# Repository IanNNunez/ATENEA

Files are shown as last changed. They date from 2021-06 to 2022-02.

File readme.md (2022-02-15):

Athena is a TKL keyboard inspired by https://github.com/coseyfannitutti/ mysterium. It uses some of cftkb's kicad libraries
as well as its USBaspLoader build. 

Known issues:
	- Diode 84 is not directly connected to the MCU, it will be fixed for the next revision.
	- Some traces near the FN key could not be completed in the manufacturing process, more clearence is needed.
	- The silkscreen for the BOOT and RESET buttons are not visible, new and clearer silkscreens will be added.
	- The MOSI and MISO pins on the MCU are swapped, does not affect the behaviour of the keyboard it needs to be taken into account when uploading the firmware. It will be fixed for the next revision.
	- The 2u backspace key is not in the correct position, it will be fixed for the next revision.

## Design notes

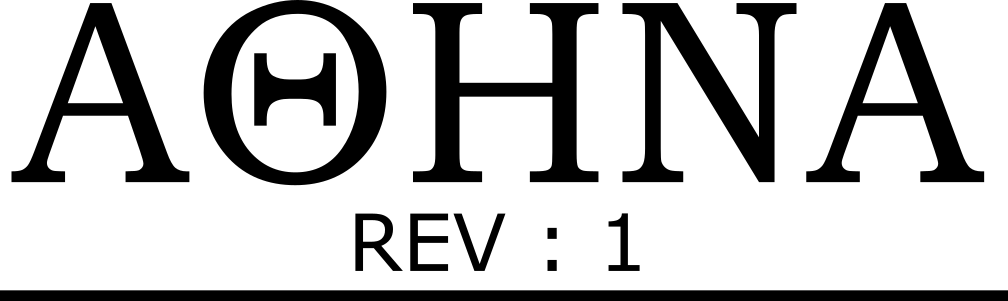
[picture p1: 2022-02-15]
AteneaTKL-pcb/Graphics/text981.png

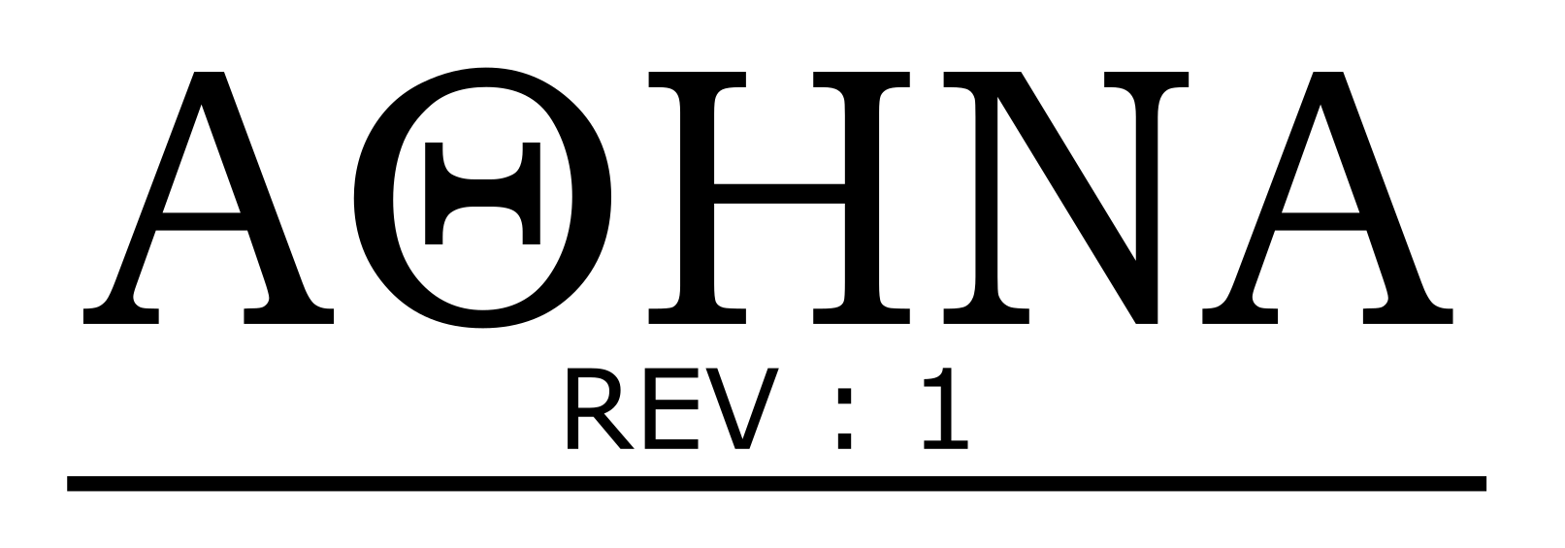
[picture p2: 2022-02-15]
AteneaTKL-pcb/Graphics/rect835.png

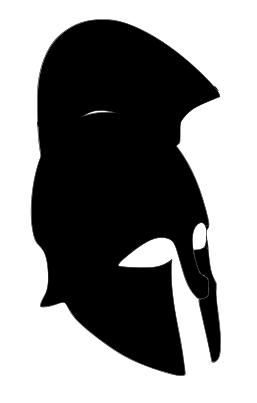
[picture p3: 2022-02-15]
AteneaTKL-pcb/Graphics/athena helmet.png

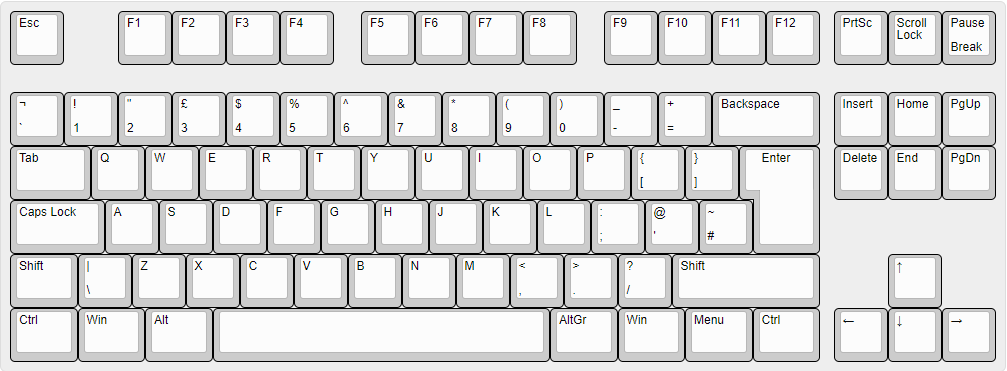
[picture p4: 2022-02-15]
AteneaTKL-pcb/Graphics/Athenea ISO.png

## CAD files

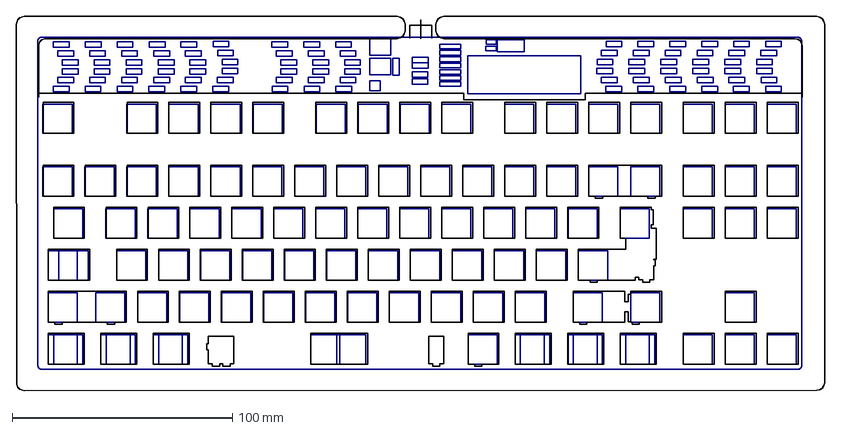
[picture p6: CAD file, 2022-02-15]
AteneaTKL-pcb/Atenea/Atenea-brd.dxf
366.7 x 169.7 mm

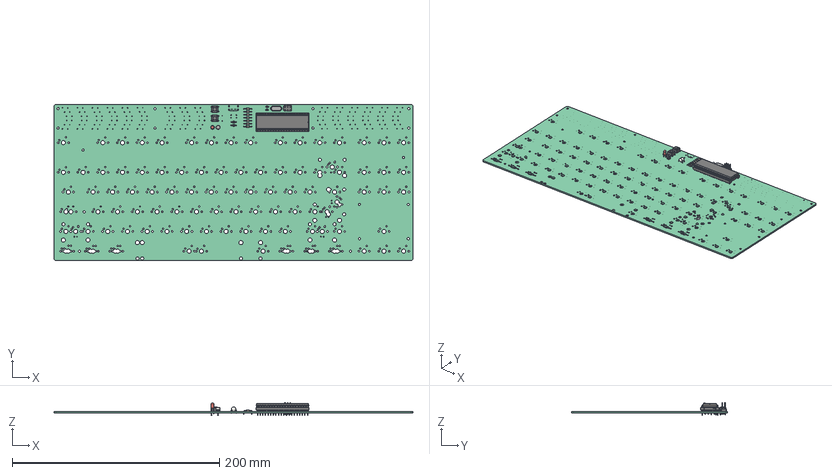
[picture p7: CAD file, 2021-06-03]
AthenaTKL case/3D RENDER/AthenaTKL_PCB.FCStd
346.7 x 150.7 x 12.3 mm
Pcb_5695
R8_R_Axial_DIN0204_L36mm_D16mm_P762mm_Horizontal_5FE505FF
LED1_LED_D3.0mm_5FE505C5
Y1_Crystal_HC49-4H_Vertical_5FE550AE
SW1_SW_PUSH_6mm_5FE54CE4
SW2_SW_PUSH_6mm_5FE5501A
J2_PinHeader_2x03_P254mm_Vertical_5FE54D8D[2]
R2_R_Axial_DIN0204_L36mm_D16mm_P762mm_Horizontal_5FE54EBF
R3_R_Axial_DIN0204_L36mm_D16mm_P762mm_Horizontal_5FE54C7C
R4_R_Axial_DIN0204_L36mm_D16mm_P762mm_Horizontal_5FE54BDD
R5_R_Axial_DIN0204_L36mm_D16mm_P762mm_Horizontal_5FE5506C
R6_R_Axial_DIN0204_L36mm_D16mm_P762mm_Horizontal_5FE54E7D
R7_R_Axial_DIN0204_L36mm_D16mm_P762mm_Horizontal_5FE518E0
C1_C_Disc_D30mm_W16mm_P250mm_5FE51B44
C3_CP_Radial_D40mm_P150mm_5FE51DCC
C5_C_Disc_D43mm_W19mm_P500mm_5FE5F764
C4_C_Disc_D43mm_W19mm_P500mm_5FE5F6FF
C2_C_Disc_D30mm_W16mm_P250mm_5FE518AA
U1_DIP-40_W15.24mm_5FE51992
U1_DIP_40_W1524mm_Socket_5FE51992[2]

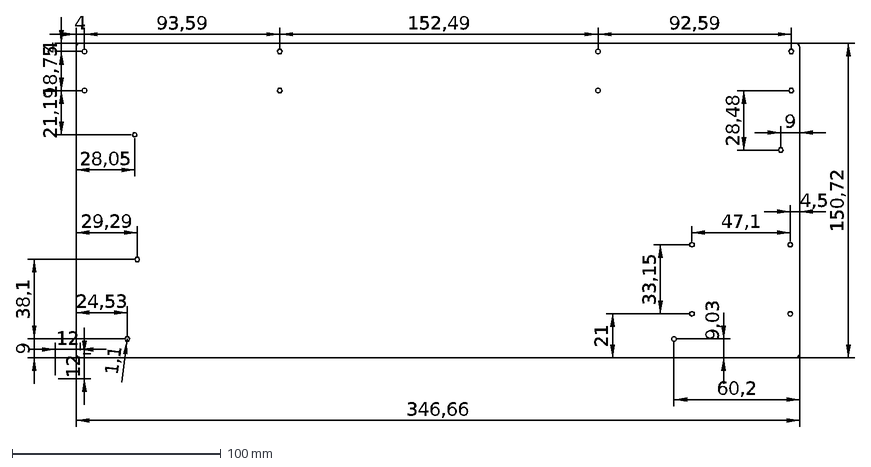
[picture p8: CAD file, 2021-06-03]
AthenaTKL case/Bottom plate.dxf
346,66
150,72
4
93,59
152,49
92,59
18,75
21,19
28,48
33,15
21
9
38,1
9,03
28,05
24,53
60,2
47,1
4,5
29,29
12
1,1

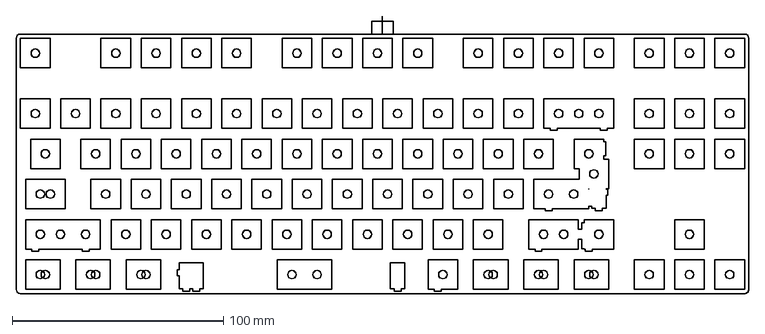
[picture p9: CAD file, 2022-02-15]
AthenaTKL case/CAD misc/TKL Leyout.dxf
346.6 x 131.2 mm

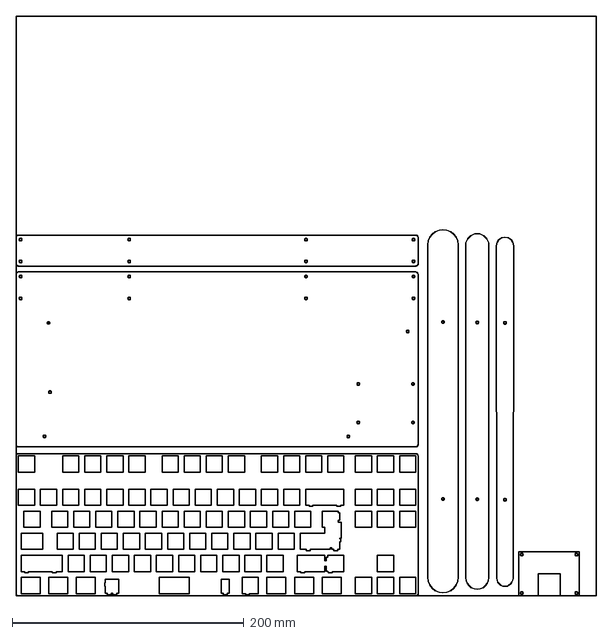
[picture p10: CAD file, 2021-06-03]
AthenaTKL case/CASE/Cut.dxf
500.0 x 500.0 mm

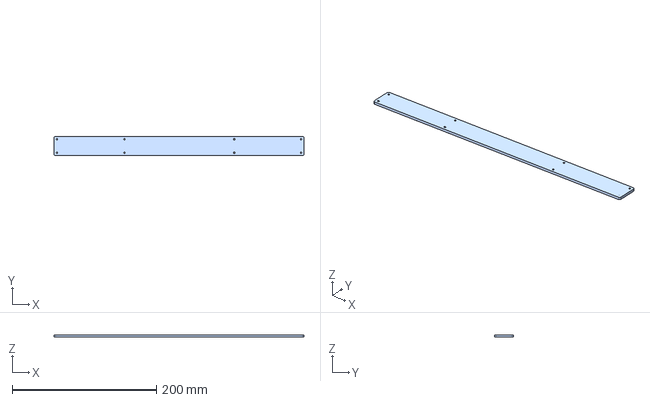
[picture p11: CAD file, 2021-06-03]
AthenaTKL case/3D RENDER/Window.FCStd
346.7 x 26.8 x 3.00 mm

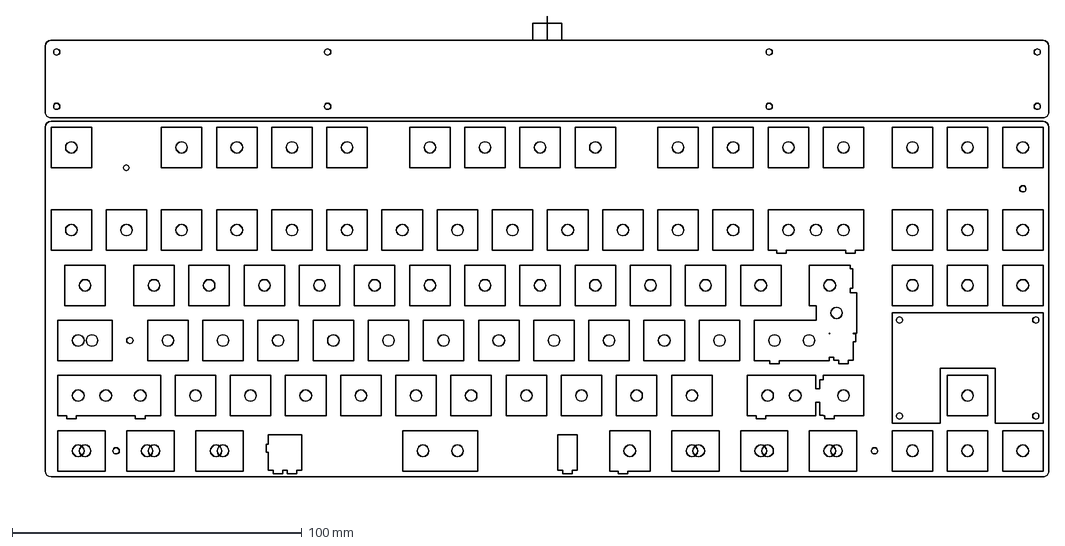
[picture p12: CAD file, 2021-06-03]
AthenaTKL case/CAD misc/TKL Leyout + Components window.dxf
356.7 x 169.2 mm

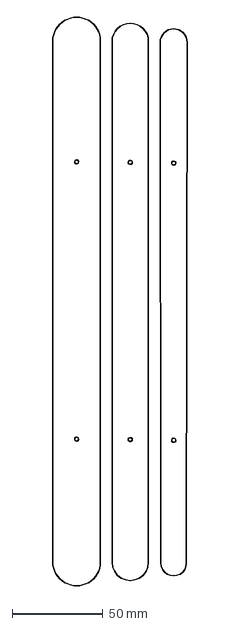
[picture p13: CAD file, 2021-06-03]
AthenaTKL case/CASE/Stand.dxf
74.0 x 314.0 mm

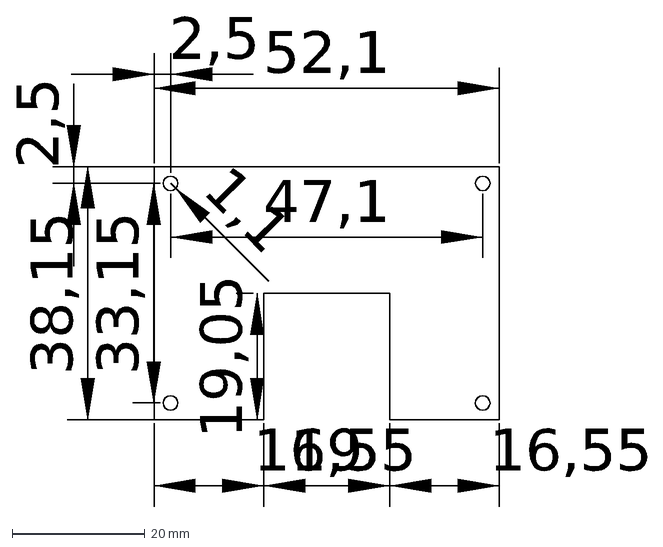
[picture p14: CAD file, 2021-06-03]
AthenaTKL case/Logo guard.dxf
52,1
16,55
19
38,15
2,5
33,15
47,1
1,1
19,05

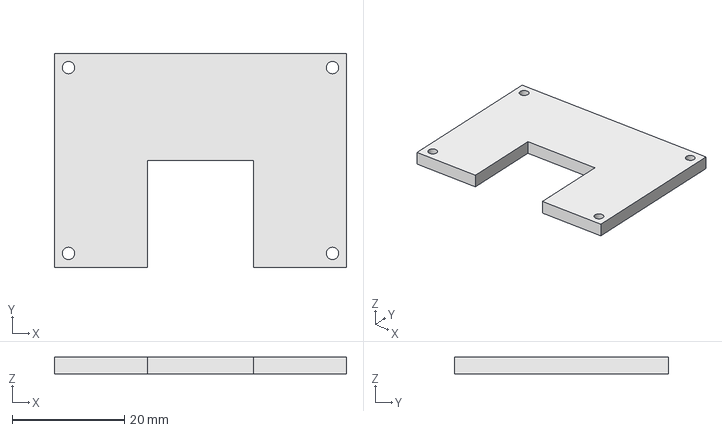
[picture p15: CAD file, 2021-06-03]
AthenaTKL case/3D RENDER/Logo guardd.FCStd
52.1 x 38.1 x 3.00 mm

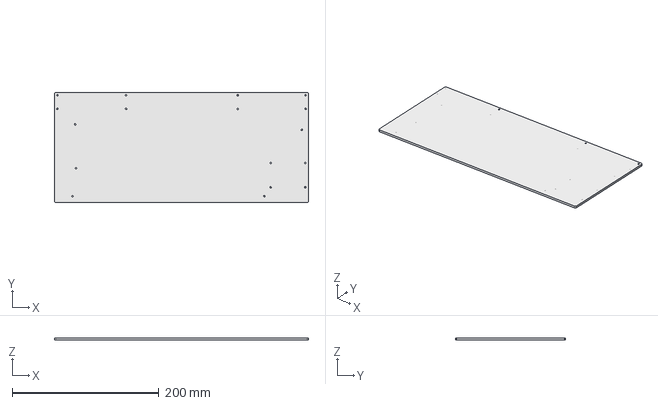
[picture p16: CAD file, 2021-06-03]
AthenaTKL case/3D RENDER/Bottom.FCStd
346.7 x 150.7 x 3.00 mm

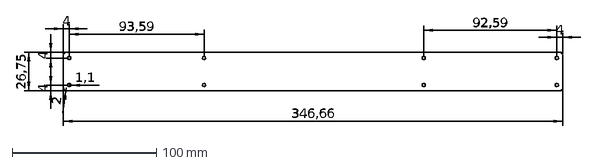
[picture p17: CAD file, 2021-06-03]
AthenaTKL case/CASE/Window.dxf
346,66
4
92,59
93,59
26,75
2
1,1

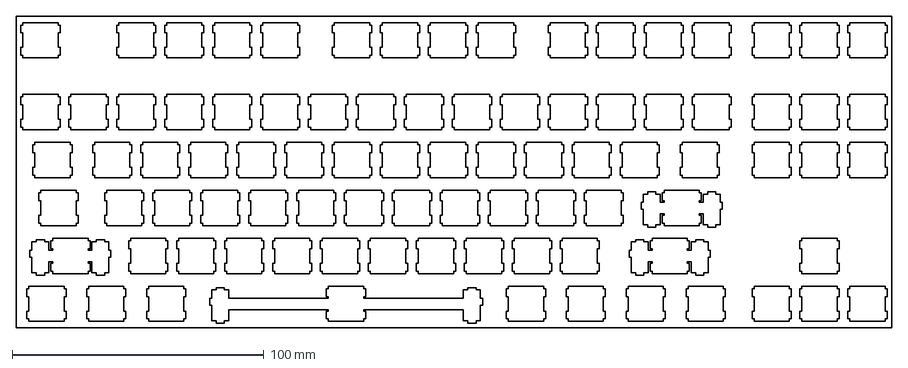
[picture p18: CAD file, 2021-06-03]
AthenaTKL case/ANSI PLATE.dxf
347.7 x 123.8 mm

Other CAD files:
AthenaTKL case/CASE/Plate.dxf

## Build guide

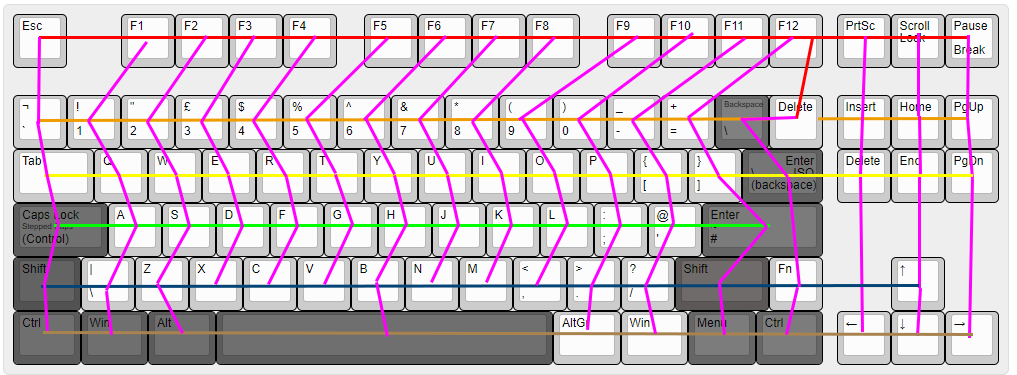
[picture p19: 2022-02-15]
AteneaTKL-pcb/Graphics/Wiring diagram.png

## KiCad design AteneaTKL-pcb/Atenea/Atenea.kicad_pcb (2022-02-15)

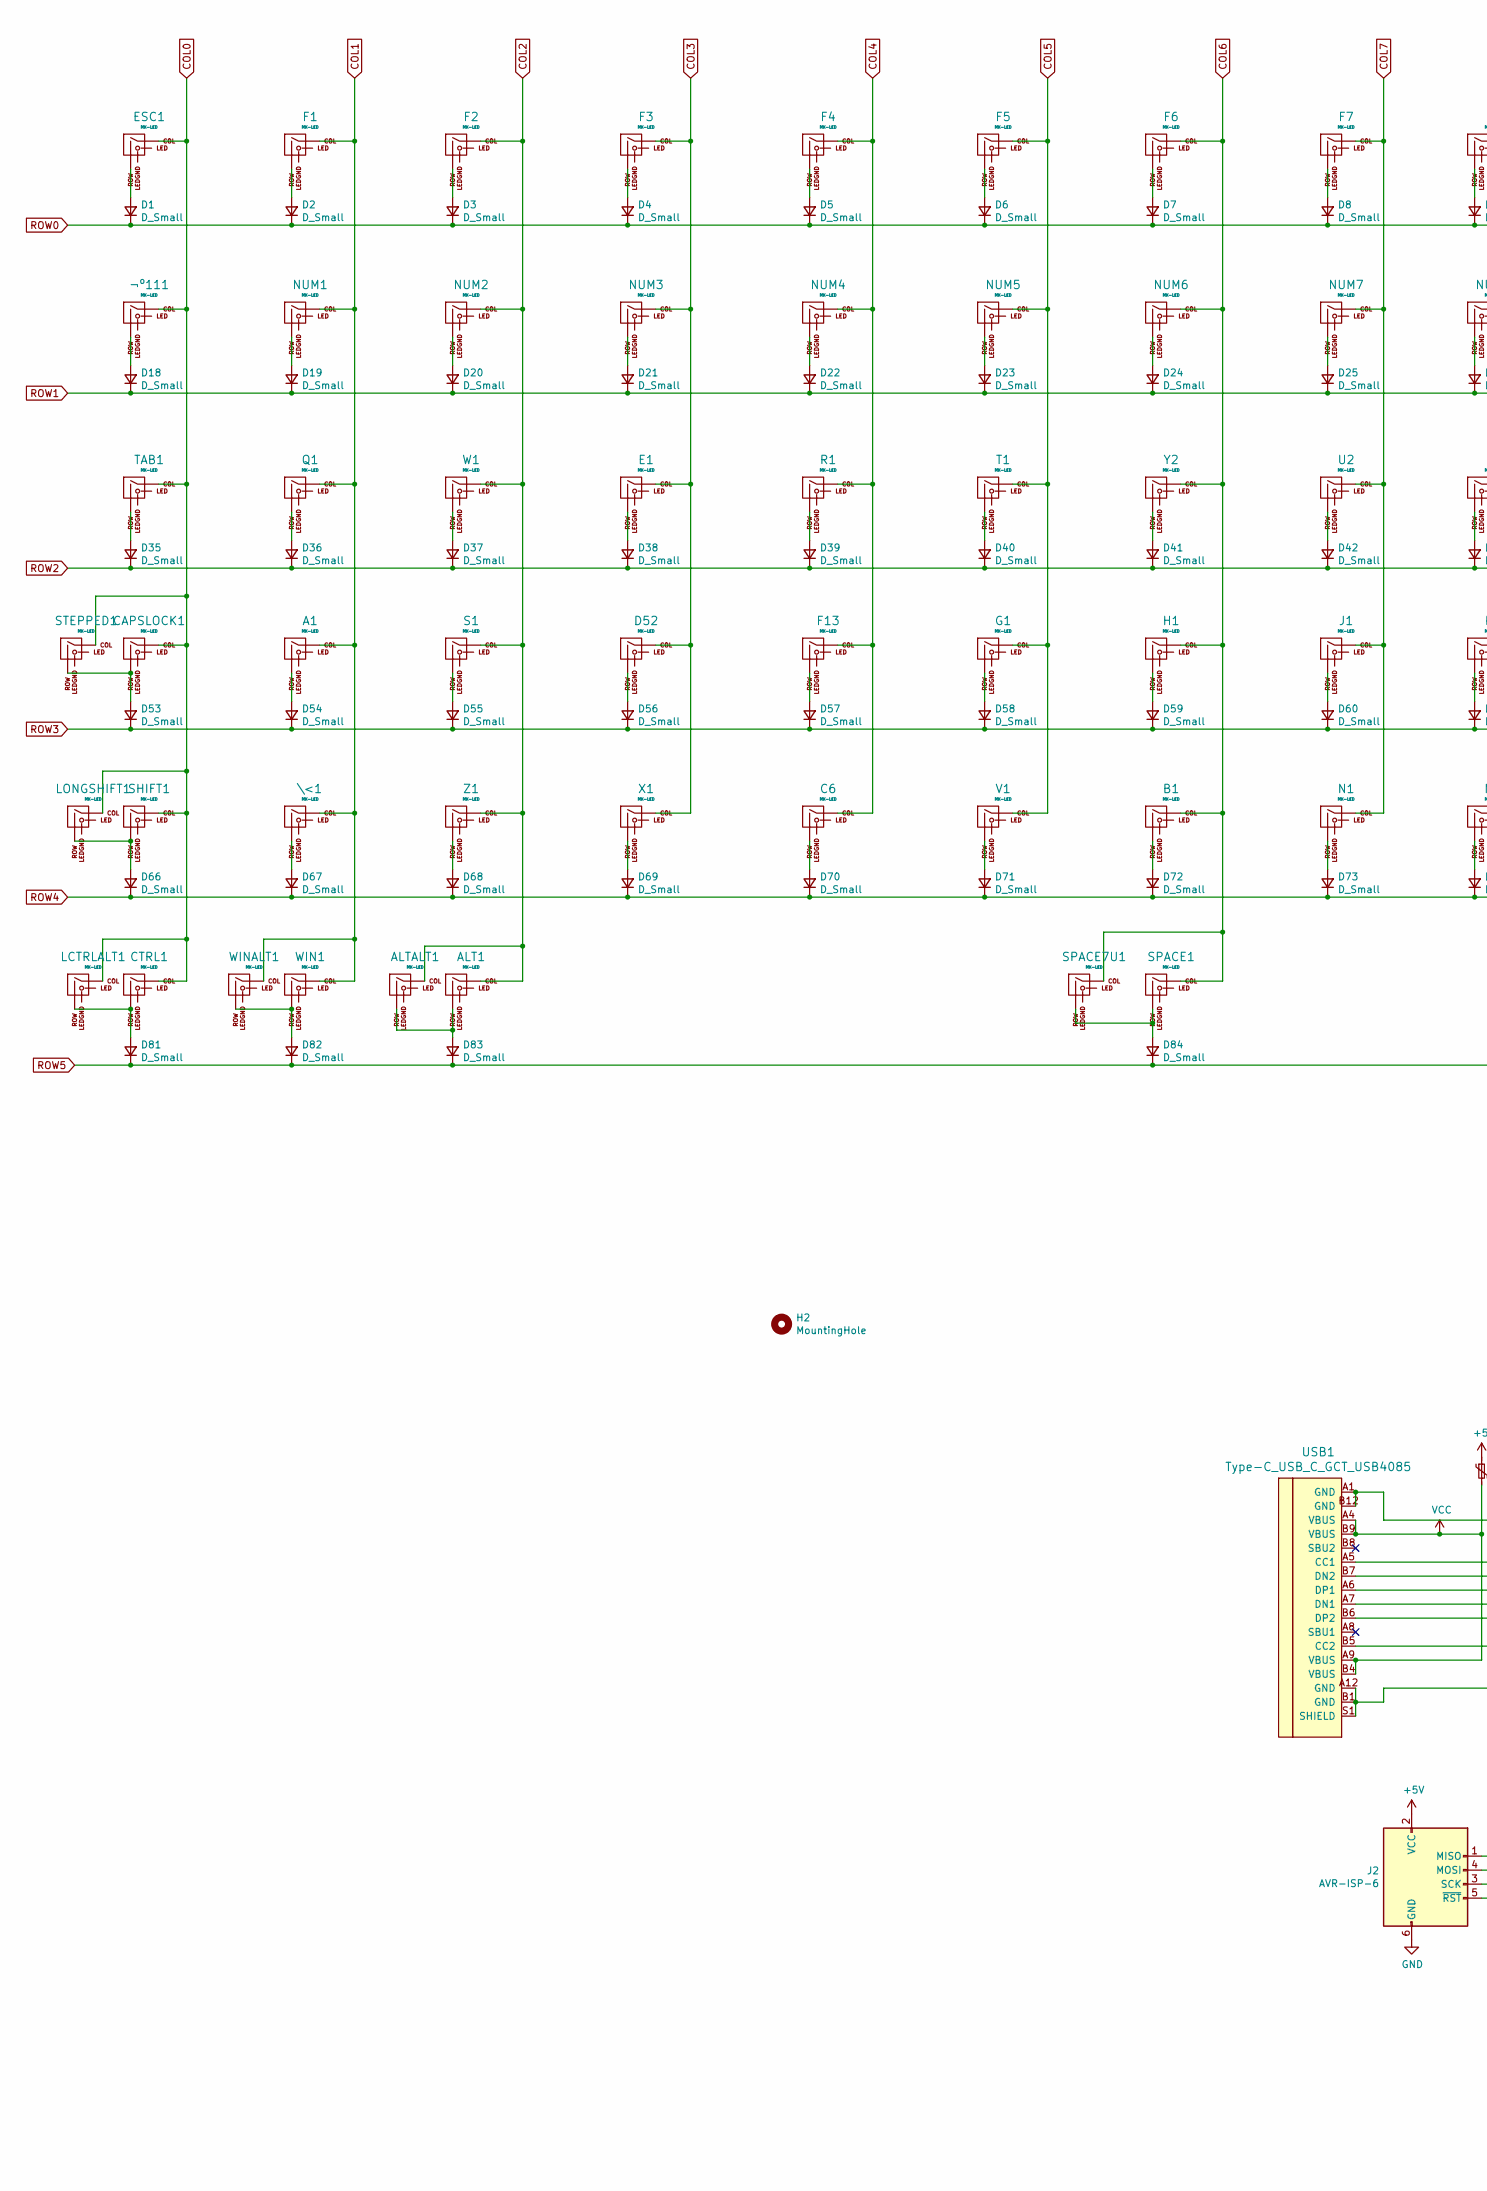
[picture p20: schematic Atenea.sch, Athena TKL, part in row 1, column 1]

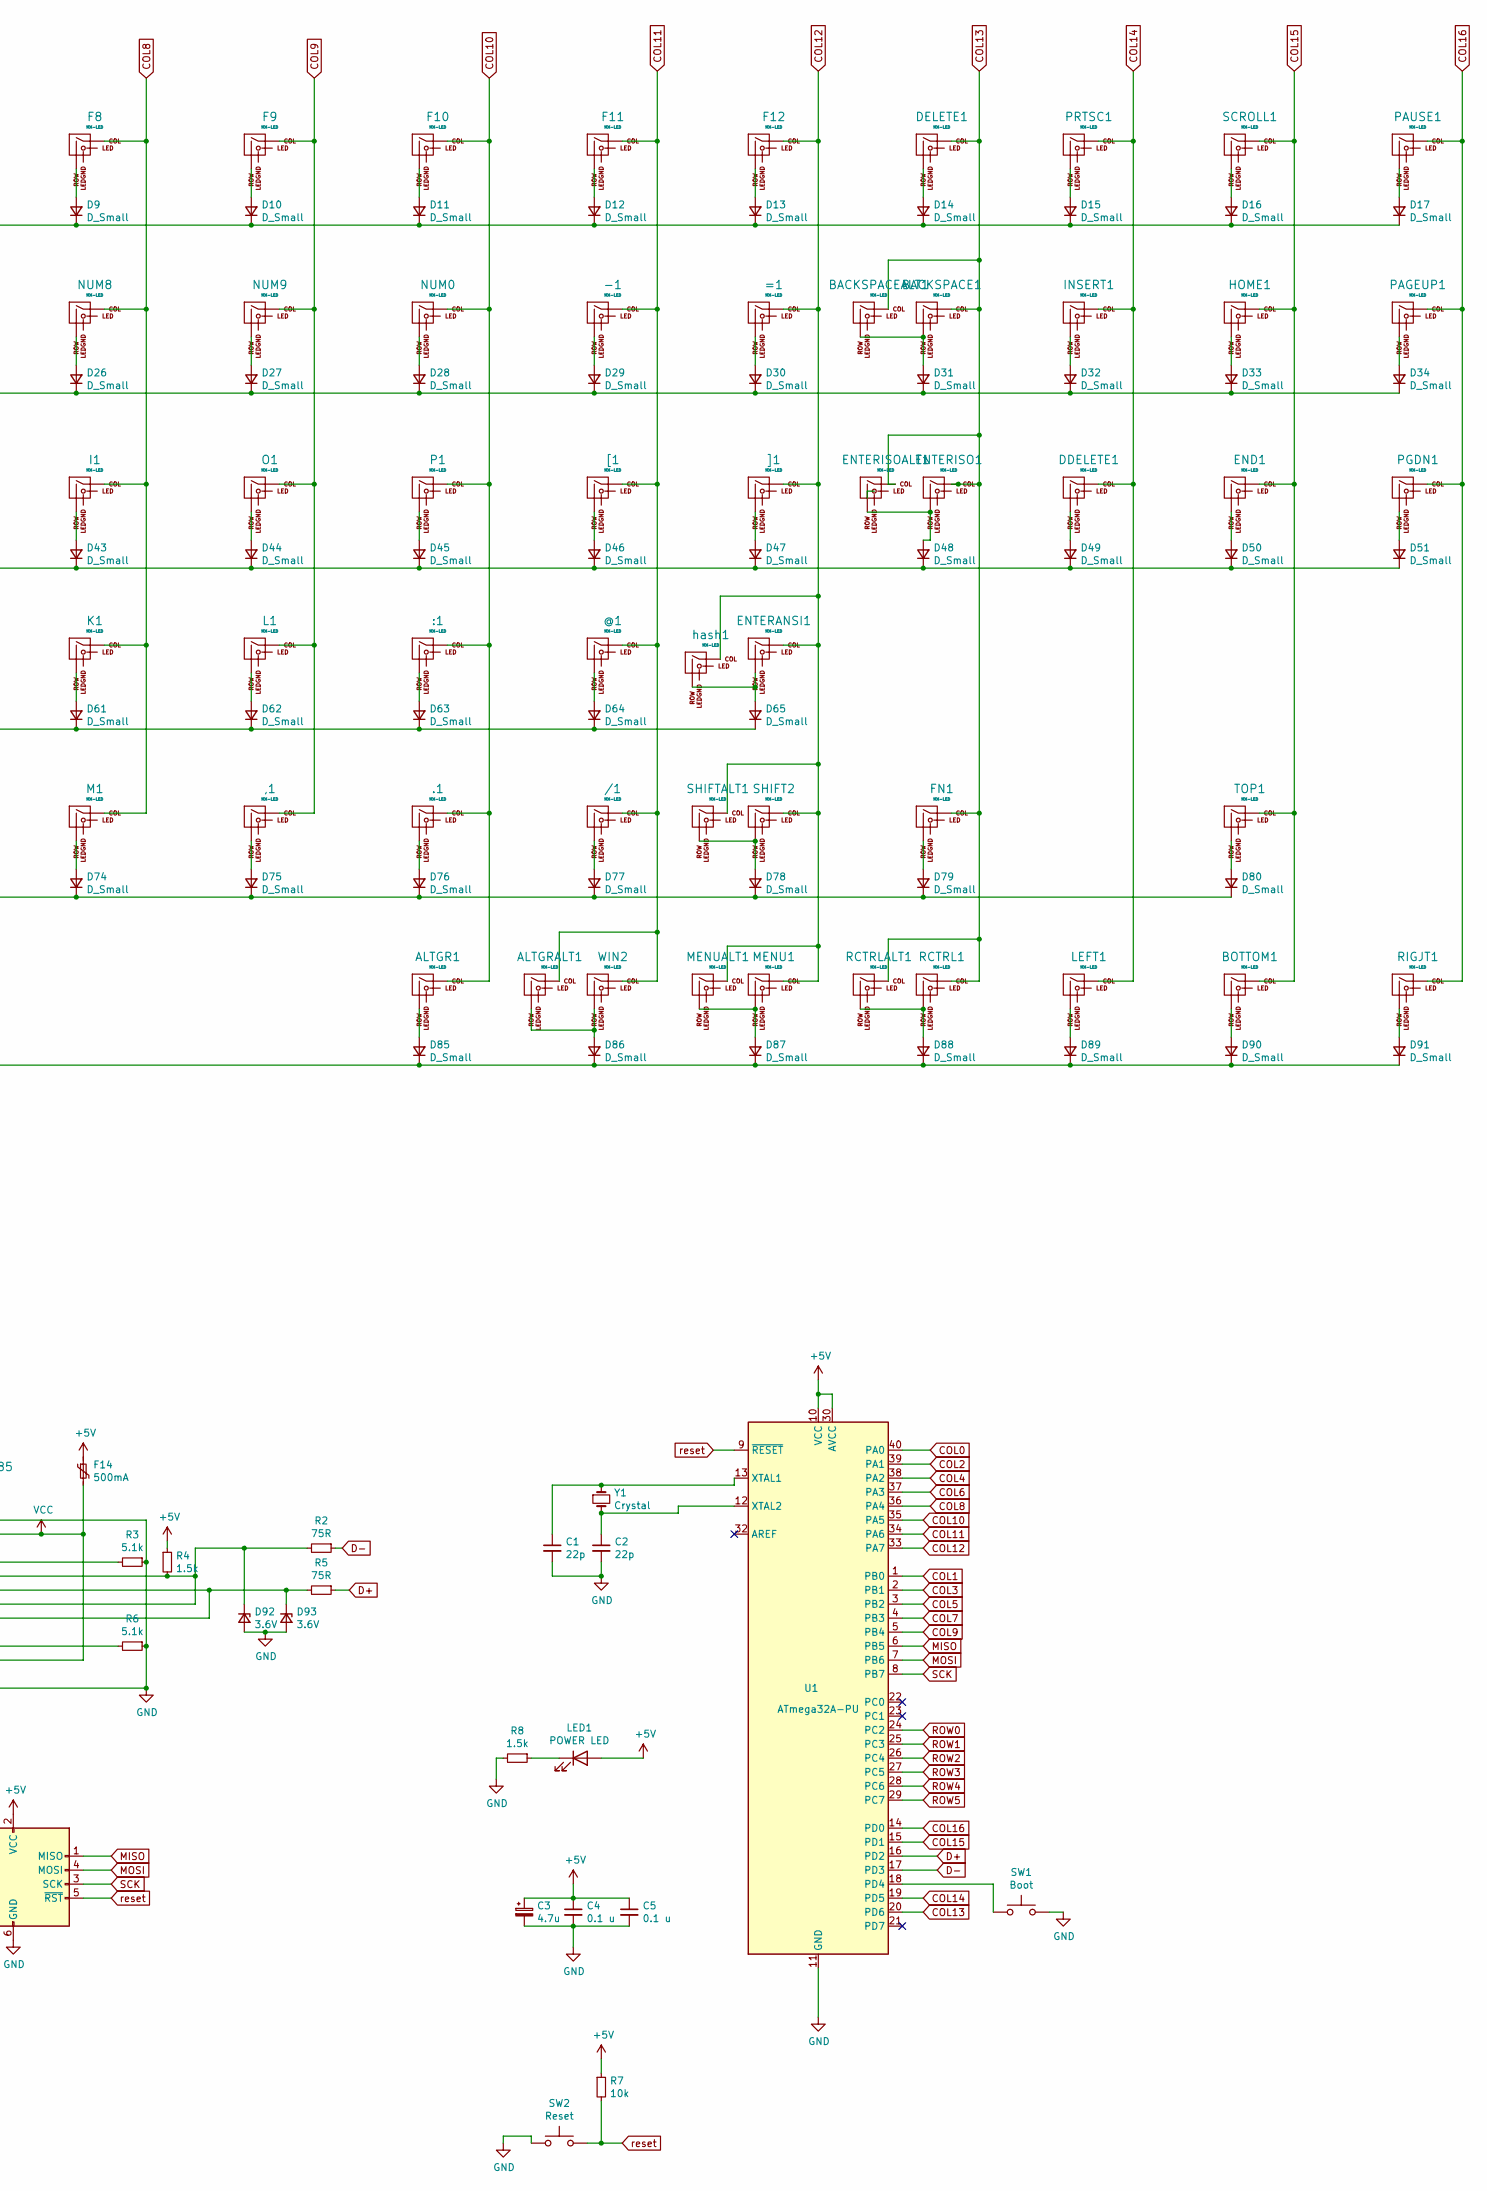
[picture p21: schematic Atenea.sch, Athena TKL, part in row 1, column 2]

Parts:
,1: MX-LED; SW_Cherry_MX_1.00u_PCB
-1: MX-LED; SW_Cherry_MX_1.00u_PCB
.1: MX-LED; SW_Cherry_MX_1.00u_PCB
/1: MX-LED; SW_Cherry_MX_1.00u_PCB
:1: MX-LED; SW_Cherry_MX_1.00u_PCB
=1: MX-LED; SW_Cherry_MX_1.00u_PCB
@1: MX-LED; SW_Cherry_MX_1.00u_PCB
A1: MX-LED; SW_Cherry_MX_1.00u_PCB
ALT1: MX-LED; SW_Cherry_MX_1.00u_PCB
ALTALT1: MX-LED; SW_Cherry_MX_1.00u_PCB
ALTGR1: MX-LED; SW_Cherry_MX_1.00u_PCB
ALTGRALT1: MX-LED; SW_Cherry_MX_1.00u_PCB
B1: MX-LED; SW_Cherry_MX_1.00u_PCB
BACKSPACE1: MX-LED; MX-2U
BACKSPACEALT1: MX-LED; SW_Cherry_MX_1.00u_PCB
BOTTOM1: MX-LED; SW_Cherry_MX_1.00u_PCB
C1, C2: 22p; C_Disc_D3.0mm_W1.6mm_P2.50mm
C3: 4.7u; CP_Radial_D4.0mm_P1.50mm
C4, C5: 0.1 u; C_Disc_D4.3mm_W1.9mm_P5.00mm
C6: MX-LED; SW_Cherry_MX_1.00u_PCB
CAPSLOCK1: MX-LED; SW_Cherry_MX_1.00u_PCB
CTRL1: MX-LED; SW_Cherry_MX_1.00u_PCB
D1, D2, D3, D4, D5, D6, D7, D8, D9, D10, D11, D12, D13, D14, D15, D16, D17, D18, D19, D20, D21, D22, D23, D24, D25, D26, D27, D28, D29, D30, D31, D32, D33, D34, D35, D36, D37, D38, D39, D40, D41, D42, D43, D44, D45, D46, D47, D48, D49, D50, D51, D53, D54, D55, D56, D57, D58, D59, D60, D61, D62, D63, D64, D65, D66, D67, D68, D69, D70, D71, D72, D73, D74, D75, D76, D77, D78, D79, D80, D81, D82, D83, D84, D85, D86, D87, D88, D89, D90, D91: D_Small; D_DO-35_SOD27_P5.08mm_Horizontal
D52: MX-LED; SW_Cherry_MX_1.00u_PCB
D92, D93: 3.6V; D_DO-35_SOD27_P5.08mm_Horizontal
DDELETE1: MX-LED; SW_Cherry_MX_1.00u_PCB
DELETE1: MX-LED; SW_Cherry_MX_1.00u_PCB
E1: MX-LED; SW_Cherry_MX_1.00u_PCB
END1: MX-LED; SW_Cherry_MX_1.00u_PCB
ENTERANSI1: MX-LED; MX-2.25U
ENTERISO1: MX-LED; MX-ISO-ReversedStabilizers
ENTERISOALT1: MX-LED; SW_Cherry_MX_1.00u_PCB
ESC1: MX-LED; SW_Cherry_MX_1.00u_PCB
F1, F2, F3, F4, F5, F6, F7, F8, F9, F10, F11, F12, F13: MX-LED; SW_Cherry_MX_1.00u_PCB
F14: 500mA; polyfuse_5.1mm
FN1: MX-LED; SW_Cherry_MX_1.00u_PCB
G1: MX-LED; SW_Cherry_MX_1.00u_PCB
H1: MX-LED; SW_Cherry_MX_1.00u_PCB
H2: MountingHole; MountingHole_2.2mm_M2
HOME1: MX-LED; SW_Cherry_MX_1.00u_PCB
I1: MX-LED; SW_Cherry_MX_1.00u_PCB
INSERT1: MX-LED; SW_Cherry_MX_1.00u_PCB
J1: MX-LED; SW_Cherry_MX_1.00u_PCB
J2: AVR-ISP-6; AVR_ICSP_3x2
K1: MX-LED; SW_Cherry_MX_1.00u_PCB
L1: MX-LED; SW_Cherry_MX_1.00u_PCB
LCTRLALT1: MX-LED; SW_Cherry_MX_1.00u_PCB
LED1: POWER LED; LED_D3.0mm
LEFT1: MX-LED; SW_Cherry_MX_1.00u_PCB
LONGSHIFT1: MX-LED; MX-2.25U
M1: MX-LED; SW_Cherry_MX_1.00u_PCB
MENU1: MX-LED; SW_Cherry_MX_1.00u_PCB
MENUALT1: MX-LED; SW_Cherry_MX_1.00u_PCB
N1: MX-LED; SW_Cherry_MX_1.00u_PCB
NUM0, NUM1, NUM2, NUM3, NUM4, NUM5, NUM6, NUM7, NUM8, NUM9: MX-LED; SW_Cherry_MX_1.00u_PCB
O1: MX-LED; SW_Cherry_MX_1.00u_PCB
P1: MX-LED; SW_Cherry_MX_1.00u_PCB
PAGEUP1: MX-LED; SW_Cherry_MX_1.00u_PCB
PAUSE1: MX-LED; SW_Cherry_MX_1.00u_PCB
PGDN1: MX-LED; SW_Cherry_MX_1.00u_PCB
PRTSC1: MX-LED; SW_Cherry_MX_1.00u_PCB
Q1: MX-LED; SW_Cherry_MX_1.00u_PCB
R1: MX-LED; SW_Cherry_MX_1.00u_PCB
R2, R5: 75R; R_Axial_DIN0204_L3.6mm_D1.6mm_P7.62mm_Horizontal
R3, R6: 5.1k; R_Axial_DIN0204_L3.6mm_D1.6mm_P7.62mm_Horizontal
R4, R8: 1.5k; R_Axial_DIN0204_L3.6mm_D1.6mm_P7.62mm_Horizontal
R7: 10k; R_Axial_DIN0204_L3.6mm_D1.6mm_P7.62mm_Horizontal
RCTRL1: MX-LED; SW_Cherry_MX_1.00u_PCB
RCTRLALT1: MX-LED; SW_Cherry_MX_1.00u_PCB
RIGJT1: MX-LED; SW_Cherry_MX_1.00u_PCB
S1: MX-LED; SW_Cherry_MX_1.00u_PCB
SCROLL1: MX-LED; SW_Cherry_MX_1.00u_PCB
SHIFT1, SHIFT2: MX-LED; SW_Cherry_MX_1.00u_PCB
SHIFTALT1: MX-LED; MX-2.75U
SPACE1, SPACE7U1: MX-LED; SW_Cherry_MX_1.00u_PCB
STEPPED1: MX-LED; SW_Cherry_MX_1.00u_PCB
SW1: Boot; SW_PUSH_6mm
SW2: Reset; SW_PUSH_6mm
T1: MX-LED; SW_Cherry_MX_1.00u_PCB
TAB1: MX-LED; SW_Cherry_MX_1.00u_PCB
TOP1: MX-LED; SW_Cherry_MX_1.00u_PCB
U1: ATmega32A-PU; DIP-40_W15.24mm
U2: MX-LED; SW_Cherry_MX_1.00u_PCB
USB1: Type-C_USB_C_GCT_USB4085; USB_C_GCT_USB4085
V1: MX-LED; SW_Cherry_MX_1.00u_PCB
W1: MX-LED; SW_Cherry_MX_1.00u_PCB
WIN1, WIN2: MX-LED; SW_Cherry_MX_1.00u_PCB
WINALT1: MX-LED; SW_Cherry_MX_1.00u_PCB
X1: MX-LED; SW_Cherry_MX_1.00u_PCB
Y1: Crystal; Crystal_HC49-4H_Vertical
Y2: MX-LED; SW_Cherry_MX_1.00u_PCB
Z1: MX-LED; SW_Cherry_MX_1.00u_PCB
[1: MX-LED; SW_Cherry_MX_1.00u_PCB
\<1: MX-LED; SW_Cherry_MX_1.00u_PCB
]1: MX-LED; SW_Cherry_MX_1.00u_PCB
hash1: MX-LED; SW_Cherry_MX_1.00u_PCB
¬º111: MX-LED; SW_Cherry_MX_1.00u_PCB

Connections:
+5V: C3.1, C4.1, C5.1, F14.1, J2.2 (VCC), LED1.2 (A), R4.1, R7.1, U1.10 (VCC), U1.30 (AVCC)
COL0: CAPSLOCK1.1 (COL), CTRL1.1 (COL), ESC1.1 (COL), LCTRLALT1.1 (COL), LONGSHIFT1.1 (COL), SHIFT1.1 (COL), STEPPED1.1 (COL), TAB1.1 (COL), U1.40 (PA0), ¬º111.1 (COL); also elsewhere on the board
COL1: A1.1 (COL), F1.1 (COL), NUM1.1 (COL), Q1.1 (COL), U1.1 (PB0), WIN1.1 (COL), WINALT1.1 (COL), \<1.1 (COL)
COL2: ALT1.1 (COL), ALTALT1.1 (COL), F2.1 (COL), NUM2.1 (COL), S1.1 (COL), U1.39 (PA1), W1.1 (COL), Z1.1 (COL)
COL3: D52.1 (COL), E1.1 (COL), F3.1 (COL), NUM3.1 (COL), U1.2 (PB1), X1.1 (COL)
COL4: C6.1 (COL), F4.1 (COL), F13.1 (COL), NUM4.1 (COL), R1.1 (COL), U1.38 (PA2)
COL5: F5.1 (COL), G1.1 (COL), NUM5.1 (COL), T1.1 (COL), U1.3 (PB2), V1.1 (COL)
COL6: B1.1 (COL), F6.1 (COL), H1.1 (COL), NUM6.1 (COL), SPACE1.1 (COL), SPACE7U1.1 (COL), U1.37 (PA3), Y2.1 (COL)
COL7: F7.1 (COL), J1.1 (COL), N1.1 (COL), NUM7.1 (COL), U1.4 (PB3), U2.1 (COL)
COL8: F8.1 (COL), I1.1 (COL), K1.1 (COL), M1.1 (COL), NUM8.1 (COL), U1.36 (PA4)
COL9: ,1.1 (COL), F9.1 (COL), L1.1 (COL), NUM9.1 (COL), O1.1 (COL), U1.5 (PB4)
COL10: .1.1 (COL), :1.1 (COL), ALTGR1.1 (COL), F10.1 (COL), NUM0.1 (COL), P1.1 (COL), U1.35 (PA5)
COL11: -1.1 (COL), /1.1 (COL), @1.1 (COL), ALTGRALT1.1 (COL), F11.1 (COL), U1.34 (PA6), WIN2.1 (COL), [1.1 (COL)
COL12: =1.1 (COL), ENTERANSI1.1 (COL), F12.1 (COL), MENU1.1 (COL), MENUALT1.1 (COL), SHIFT2.1 (COL), SHIFTALT1.1 (COL), U1.33 (PA7), ]1.1 (COL), hash1.1 (COL)
COL13: BACKSPACE1.1 (COL), BACKSPACEALT1.1 (COL), DELETE1.1 (COL), ENTERISO1.1 (COL), ENTERISOALT1.1 (COL), FN1.1 (COL), RCTRL1.1 (COL), RCTRLALT1.1 (COL), U1.20 (PD6)
COL14: DDELETE1.1 (COL), INSERT1.1 (COL), LEFT1.1 (COL), PRTSC1.1 (COL), U1.19 (PD5)
COL15: BOTTOM1.1 (COL), END1.1 (COL), HOME1.1 (COL), SCROLL1.1 (COL), TOP1.1 (COL), U1.15 (PD1)
COL16: PAGEUP1.1 (COL), PAUSE1.1 (COL), PGDN1.1 (COL), RIGJT1.1 (COL), U1.14 (PD0)
D+: R5.1, U1.16 (PD2)
D-: R2.1, U1.17 (PD3)
GND: C1.2, C2.2, C3.2, C4.2, C5.2, D92.2 (A), D93.2 (A), J2.6 (GND), R3.1, R6.1, R8.2, SW1.2, SW2.1, U1.11 (GND), U1.31 (GND), USB1.A1 (GND), USB1.A12 (GND), USB1.B1 (GND), USB1.B12 (GND), USB1.S1 (SHIELD)
MISO: J2.1 (MISO), U1.6 (PB5)
MOSI: J2.4 (MOSI), U1.7 (PB6)
unnamed: ,1.2 (ROW), D75.2 (A)
unnamed: -1.2 (ROW), D29.2 (A)
unnamed: .1.2 (ROW), D76.2 (A)
unnamed: /1.2 (ROW), D77.2 (A)
unnamed: :1.2 (ROW), D63.2 (A)
unnamed: =1.2 (ROW), D30.2 (A)
unnamed: @1.2 (ROW), D64.2 (A)
unnamed: A1.2 (ROW), D54.2 (A)
unnamed: ALT1.2 (ROW), ALTALT1.2 (ROW), D83.2 (A)
unnamed: ALTGR1.2 (ROW), D85.2 (A)
unnamed: ALTGRALT1.2 (ROW), D86.2 (A), WIN2.2 (ROW)
unnamed: B1.2 (ROW), D72.2 (A)
unnamed: BACKSPACE1.2 (ROW), BACKSPACEALT1.2 (ROW), D31.2 (A)
unnamed: BOTTOM1.2 (ROW), D90.2 (A)
unnamed: C1.1, U1.13 (XTAL1), Y1.1
unnamed: C2.1, U1.12 (XTAL2), Y1.2
unnamed: C6.2 (ROW), D70.2 (A)
unnamed: CAPSLOCK1.2 (ROW), D53.2 (A), STEPPED1.2 (ROW)
unnamed: CTRL1.2 (ROW), D81.2 (A), LCTRLALT1.2 (ROW)
unnamed: D1.2 (A), ESC1.2 (ROW)
unnamed: D2.2 (A), F1.2 (ROW)
unnamed: D3.2 (A), F2.2 (ROW)
unnamed: D4.2 (A), F3.2 (ROW)
unnamed: D5.2 (A), F4.2 (ROW)
unnamed: D6.2 (A), F5.2 (ROW)
unnamed: D7.2 (A), F6.2 (ROW)
unnamed: D8.2 (A), F7.2 (ROW)
unnamed: D9.2 (A), F8.2 (ROW)
unnamed: D10.2 (A), F9.2 (ROW)
unnamed: D11.2 (A), F10.2 (ROW)
unnamed: D12.2 (A), F11.2 (ROW)
unnamed: D13.2 (A), F12.2 (ROW)
unnamed: D14.2 (A), DELETE1.2 (ROW)
unnamed: D15.2 (A), PRTSC1.2 (ROW)
unnamed: D16.2 (A), SCROLL1.2 (ROW)
unnamed: D17.2 (A), PAUSE1.2 (ROW)
unnamed 61: D18.2 (A), ¬º111.2 (ROW); also elsewhere on the board
unnamed: D19.2 (A), NUM1.2 (ROW)
unnamed: D20.2 (A), NUM2.2 (ROW)
unnamed: D21.2 (A), NUM3.2 (ROW)
unnamed: D22.2 (A), NUM4.2 (ROW)
unnamed: D23.2 (A), NUM5.2 (ROW)
unnamed: D24.2 (A), NUM6.2 (ROW)
unnamed: D25.2 (A), NUM7.2 (ROW)
unnamed: D26.2 (A), NUM8.2 (ROW)
unnamed: D27.2 (A), NUM9.2 (ROW)
unnamed: D28.2 (A), NUM0.2 (ROW)
unnamed: D32.2 (A), INSERT1.2 (ROW)
unnamed: D33.2 (A), HOME1.2 (ROW)
unnamed: D34.2 (A), PAGEUP1.2 (ROW)
unnamed: D35.2 (A), TAB1.2 (ROW)
unnamed: D36.2 (A), Q1.2 (ROW)
unnamed: D37.2 (A), W1.2 (ROW)
unnamed: D38.2 (A), E1.2 (ROW)
unnamed: D39.2 (A), R1.2 (ROW)
unnamed: D40.2 (A), T1.2 (ROW)
unnamed: D41.2 (A), Y2.2 (ROW)
unnamed: D42.2 (A), U2.2 (ROW)
unnamed: D43.2 (A), I1.2 (ROW)
unnamed: D44.2 (A), O1.2 (ROW)
unnamed: D45.2 (A), P1.2 (ROW)
unnamed: D46.2 (A), [1.2 (ROW)
unnamed: D47.2 (A), ]1.2 (ROW)
unnamed: D48.2 (A), ENTERISO1.2 (ROW), ENTERISOALT1.2 (ROW)
unnamed: D49.2 (A), DDELETE1.2 (ROW)
unnamed: D50.2 (A), END1.2 (ROW)
unnamed: D51.2 (A), PGDN1.2 (ROW)
unnamed: D52.2 (ROW), D56.2 (A)
unnamed: D55.2 (A), S1.2 (ROW)
unnamed: D57.2 (A), F13.2 (ROW)
unnamed: D58.2 (A), G1.2 (ROW)
unnamed: D59.2 (A), H1.2 (ROW)
unnamed: D60.2 (A), J1.2 (ROW)
unnamed: D61.2 (A), K1.2 (ROW)
unnamed: D62.2 (A), L1.2 (ROW)
unnamed: D65.2 (A), ENTERANSI1.2 (ROW), hash1.2 (ROW)
unnamed: D66.2 (A), LONGSHIFT1.2 (ROW), SHIFT1.2 (ROW)
unnamed: D67.2 (A), \<1.2 (ROW)
unnamed: D68.2 (A), Z1.2 (ROW)
unnamed: D69.2 (A), X1.2 (ROW)
unnamed: D71.2 (A), V1.2 (ROW)
unnamed: D73.2 (A), N1.2 (ROW)
unnamed: D74.2 (A), M1.2 (ROW)
unnamed: D78.2 (A), SHIFT2.2 (ROW), SHIFTALT1.2 (ROW)
unnamed: D79.2 (A), FN1.2 (ROW)
unnamed: D80.2 (A), TOP1.2 (ROW)
unnamed: D82.2 (A), WIN1.2 (ROW), WINALT1.2 (ROW)
unnamed: D84.2 (A), SPACE1.2 (ROW), SPACE7U1.2 (ROW)
unnamed: D87.2 (A), MENU1.2 (ROW), MENUALT1.2 (ROW)
unnamed: D88.2 (A), RCTRL1.2 (ROW), RCTRLALT1.2 (ROW)
unnamed: D89.2 (A), LEFT1.2 (ROW)
unnamed: D91.2 (A), RIGJT1.2 (ROW)
unnamed: D92.1 (K), R2.2, R4.2, USB1.A7 (DN1), USB1.B7 (DN2)
unnamed: D93.1 (K), R5.2, USB1.A6 (DP1), USB1.B6 (DP2)
unnamed: LED1.1 (K), R8.1
unnamed: R3.2, USB1.A5 (CC1)
unnamed: R6.2, USB1.B5 (CC2)
unnamed: SW1.1, U1.18 (PD4)
ROW0: D1.1 (K), D2.1 (K), D3.1 (K), D4.1 (K), D5.1 (K), D6.1 (K), D7.1 (K), D8.1 (K), D9.1 (K), D10.1 (K), D11.1 (K), D12.1 (K), D13.1 (K), D14.1 (K), D15.1 (K), D16.1 (K), D17.1 (K), U1.24 (PC2)
ROW1: D18.1 (K), D19.1 (K), D20.1 (K), D21.1 (K), D22.1 (K), D23.1 (K), D24.1 (K), D25.1 (K), D26.1 (K), D27.1 (K), D28.1 (K), D29.1 (K), D30.1 (K), D31.1 (K), D32.1 (K), D33.1 (K), D34.1 (K), U1.25 (PC3)
ROW2: D35.1 (K), D36.1 (K), D37.1 (K), D38.1 (K), D39.1 (K), D40.1 (K), D41.1 (K), D42.1 (K), D43.1 (K), D44.1 (K), D45.1 (K), D46.1 (K), D47.1 (K), D48.1 (K), D49.1 (K), D50.1 (K), D51.1 (K), U1.26 (PC4)
ROW3: D53.1 (K), D54.1 (K), D55.1 (K), D56.1 (K), D57.1 (K), D58.1 (K), D59.1 (K), D60.1 (K), D61.1 (K), D62.1 (K), D63.1 (K), D64.1 (K), D65.1 (K), U1.27 (PC5)
ROW4: D66.1 (K), D67.1 (K), D68.1 (K), D69.1 (K), D70.1 (K), D71.1 (K), D72.1 (K), D73.1 (K), D74.1 (K), D75.1 (K), D76.1 (K), D77.1 (K), D78.1 (K), D79.1 (K), D80.1 (K), U1.28 (PC6)
ROW5: D81.1 (K), D82.1 (K), D83.1 (K), D84.1 (K), D85.1 (K), D86.1 (K), D87.1 (K), D88.1 (K), D89.1 (K), D90.1 (K), D91.1 (K), U1.29 (PC7)
SCK: J2.3 (SCK), U1.8 (PB7)
VCC: F14.2, USB1.A4 (VBUS), USB1.A9 (VBUS), USB1.B4 (VBUS), USB1.B9 (VBUS)
reset: J2.5 (~RST), R7.2, SW2.2, U1.9 (~RESET)

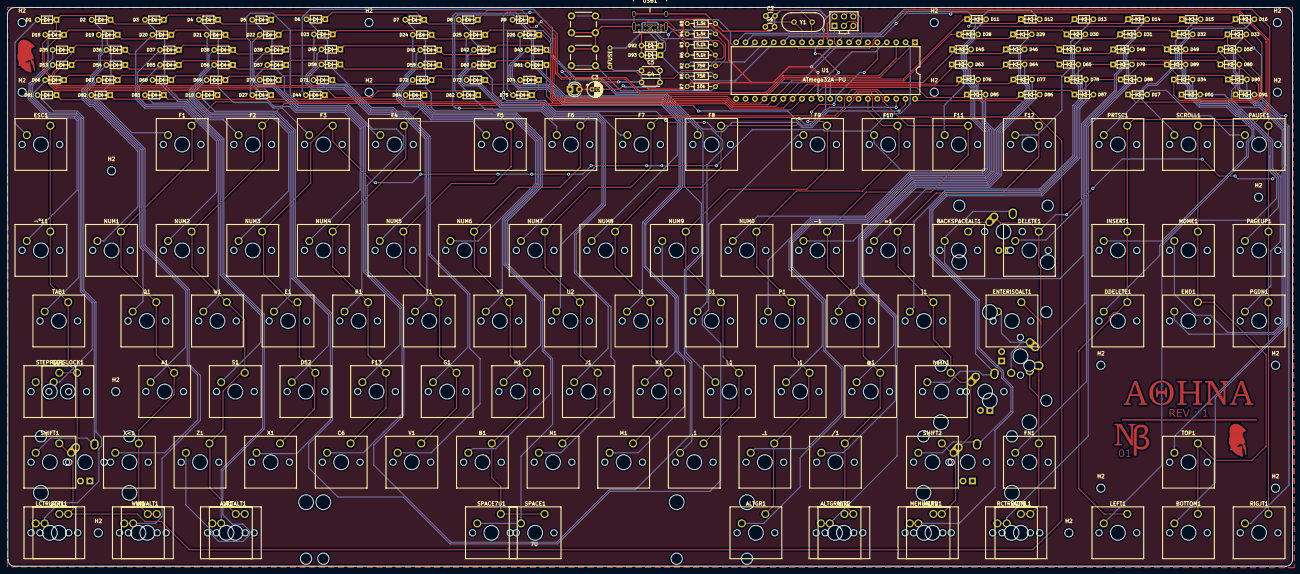
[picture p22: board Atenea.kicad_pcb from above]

Board: 2 copper layers, 346.7 x 150.7 mm, 238 parts (0 on the bottom side), 130 nets.

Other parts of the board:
G2, G6: LOGO; athena helmet negative
G4: LOGO; athena logo
G5: LOGO; NEWblack logo
H2#2, H2#3, H2#4, H2#5, H2#6, H2#7, H2#8, H2#9, H2#10, H2#11, H2#12, H2#13, H2#14, H2#15, H2#16, H2#17: MountingHole; MountingHole_2.2mm_M2
ST62: 7U; MX-7U-Stabilizer
ST62#2: 6.25U; MX-6.25U-Stabilizer
¬º11: MX-LED; SW_Cherry_MX_1.00u_PCB

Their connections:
COL0: ¬º11.1; also elsewhere on the board
unnamed 61: ¬º11.2; also elsewhere on the board

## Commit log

2021-06-03 Proyect updated and uploaded
    [ANSI PLATE.dxf, AthenaTKL_PCB.FCStd, Bottom plate.dxf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]
2022-02-15 Added pcb files and clean up
    [#TKL Leyout + Components window.dxf, ANSI PLATE.dxf, Atenea 3d.FCStd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]
2022-02-15 Create AteneaTKL-pcb
2022-02-15 Revert "Delete AteneaTKL-pcb"
    This reverts commit ce965d91c7369113902de39412e0e9e35ef7db22.
    [#TKL Leyout + Components window.dxf, ANSI PLATE.dxf, Atenea 3d.FCStd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]
2022-02-15 Clean up
    [ANSI PLATE.dxf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]
2022-02-15 PCB files
